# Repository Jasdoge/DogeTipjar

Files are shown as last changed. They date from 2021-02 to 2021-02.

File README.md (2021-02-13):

# DogeTipjar
A fancy dog-based internet currency tipjar

# Parts needed

* 1000 uF Capacitor (suggested 10V+)
* [ESP32 Dev board](https://www.aliexpress.com/item/32866131814.html) - You can use any ESP32 board style, but the 3D printed case was designed for that particular style
* [DFPlayer Mini](https://www.aliexpress.com/item/32657798948.html)
* SD Card for your DFPlayer
* [Small speaker](https://www.aliexpress.com/item/32901680862.html)
* [TFT Touch Screen](https://www.aliexpress.com/item/32960934541.html) - The one I used is using the ILI9341 for control and 320x240 resolution. You can use other styles if you want to edit the images & code.
* Wires

# Schematics
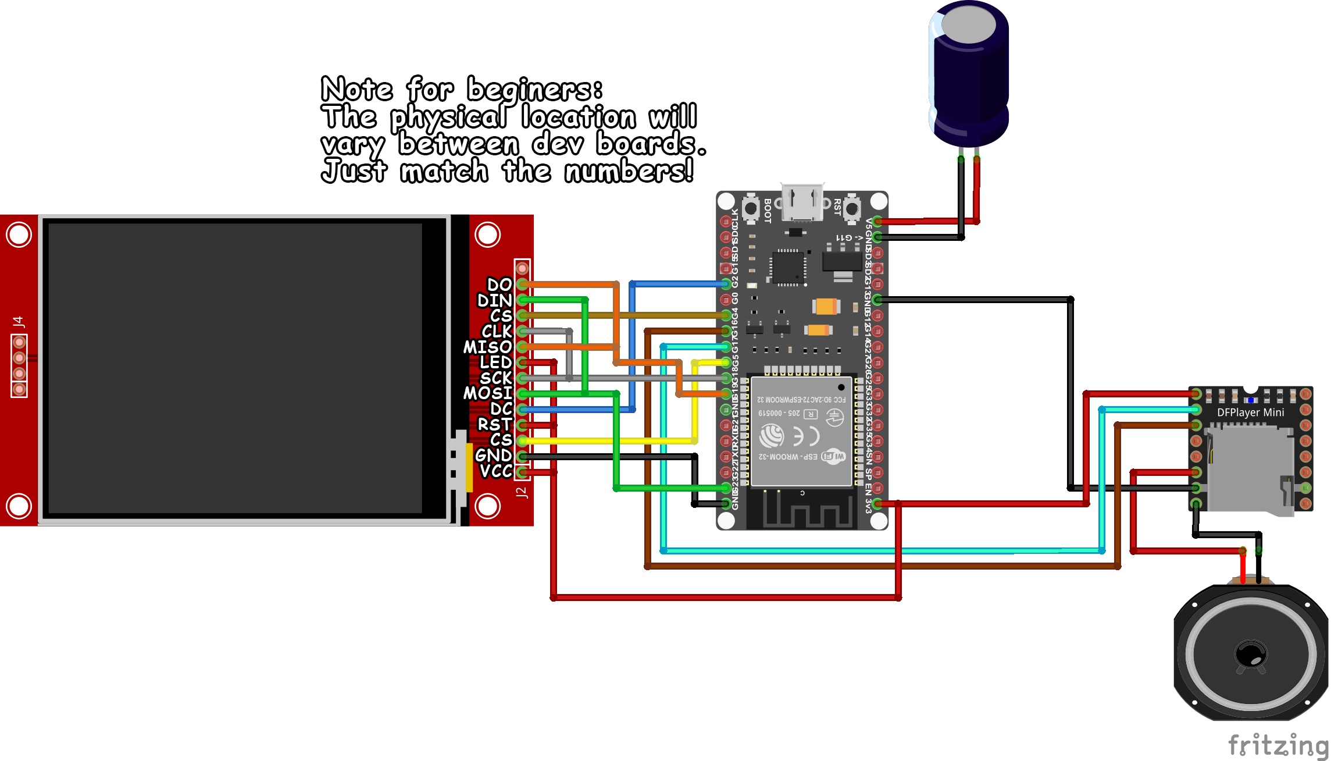
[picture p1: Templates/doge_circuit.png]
Schematics


## Touchscreen

| Screen Pin(s) | ESP Pin | Note |
|---|---|---|
| VCC, LED, RST | 3v3 | Power supply |
| GND | gnd | ESP ground, all grounds are tied together |
| CS | IO5 | Chip select for screen |
| DC | IO2 | |
| SDI (MOSI), DIN (Touch) | 23 | SPI |
| SCK, CLK (Touch) | 18 | SPI Clock |
| MISO, DO | 19 | SPI |
| IRQ (touch) | Not connected | Can be used for interrupts |
| CS | 4 | Chip select for touch |

## DFPlayer Mini

DFPlayer
| Speaker Pin | ESP Pin | Note |
|---|---|---|
| 1 (VCC) | 3v3 | Power supply |
| 2 (RX) | 17 | UART |
| 3 (TX) | 16 | UART |
| 6 | Connect to speaker | Either pole on the speaker will work |
| 7 | GND | Connect to any ground, all grounds are tied together |
| 8 | Connecto to speaker | 6 and 8 should be connected to one pole each of the speaker | 

Protip: On the bottom of the DFPlayer next to the 8-pin chip directly under the SD card is a 0-ohm resistor. If you remove that and short the unsoldered jumper on the right side of the chip, it'll draw much less current in standby.

## Capacitor

Connect a 100-1000uF capacitor with the positive end (long leg) on 5V of the ESP32, and short leg on GND. This will help reduce screen flicker and brownouts on the DFPlayer. 

# How to program

1. [Install Arduino](https://www.arduino.cc/)
2. [Install ESP32 board](https://github.com/espressif/arduino-esp32)
3. [Install the ESP32 filesystem uploader](https://randomnerdtutorials.com/install-esp32-filesystem-uploader-arduino-ide/)
4. Install the following libraries using the Arduino library manager:
	* TFT_eSPI. This one needs you to edit a User_Setup.h library file for your board. There's an example User_Setup.h in the Templates folder setup for the ILI9341 screen that I use in this project. For more info [see the library](https://github.com/Bodmer/TFT_eSPI). 
	* QRCode
	* ArduinoJson
	* ArduinoWebsockets
	* DFPlayerMini_Fast
5. Set your board appropriately in Arduino. I use ESP32 Dev module, No OTA (2MB App/2MB FATFS)
6. Open the TipJar.ino file in Arduino.
7. Plug in your arduino to your computer and select the com port in the tools menu.
8. Go to Tools -> ESP32 Sketch data upload. This should upload all the image files and font to your ESP32.
9. Audio: Format your SD card to FAT32.
10. Find the audio files in the Audio folder. The files need to be pasted in a specific order. Look at Instructions.txt in the Audio folder for the correct sequence.
11. Plug the SD card into the DFPlayer.
12. Compile and upload by hitting the Arrow button in Arduino.

# Case

The STL folder has the 3d prints. It's very simple and requires you to use hot glue to attach the screen. Feel free to make a better one!

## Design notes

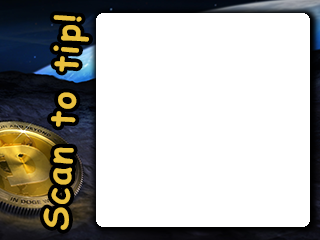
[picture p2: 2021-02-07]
Templates/qr.bmp

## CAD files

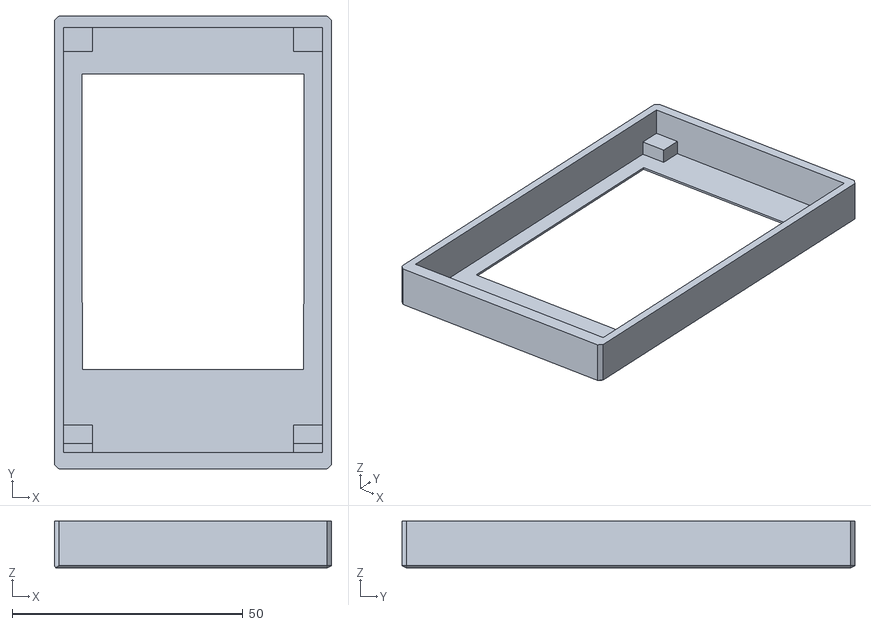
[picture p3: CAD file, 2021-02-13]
STL/screenholder.STL
60.0 x 98.1 x 10.1

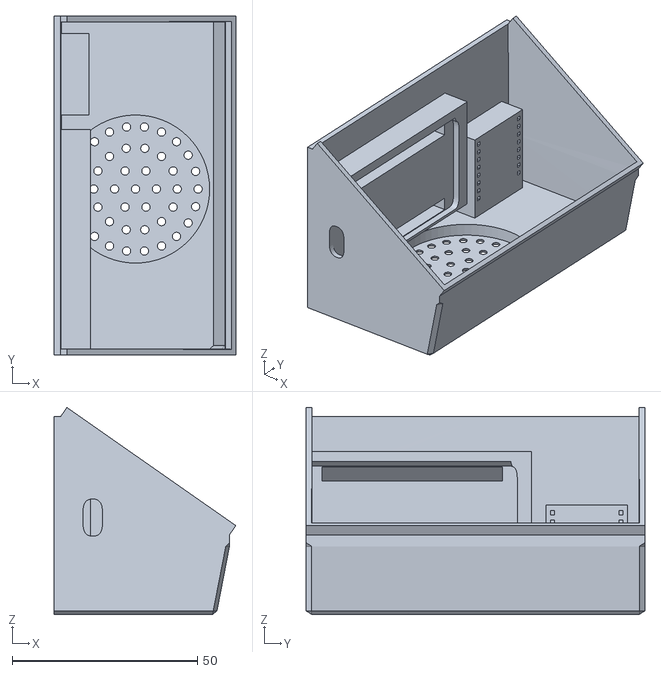
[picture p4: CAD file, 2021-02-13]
STL/dogebox_base.STL
49.1 x 91.6 x 55.9

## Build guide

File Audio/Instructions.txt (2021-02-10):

Note: The order you paste these into your SD card matters!

1. Format your SD card to FAT32
2. Copy and paste the files onto the card one by one in the following order:
	1. dogetip_big.mp3
	2. dogetip_med.mp3
	3. dogetip_small.mp3
	4. click.mp3

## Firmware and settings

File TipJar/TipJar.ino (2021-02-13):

/*
	Edit Configuration.h
	Don't forget to edit your TFT_eSPI config in libraries
	You can find a template in Templates

	Libraries:
	https://github.com/Bodmer/TFT_eSPI
	https://github.com/ricmoo/QRCode
	https://github.com/bblanchon/ArduinoJson
	https://github.com/gilmaimon/ArduinoWebsockets
	https://github.com/PowerBroker2/DFPlayerMini_Fast


	Audio credits 
	https://freesound.org/people/Robinhood76/sounds/63814/
	https://freesound.org/people/clairinski/sounds/184372/
	https://freesound.org/people/Anthousai/sounds/336578/
	https://freesound.org/people/EminYILDIRIM/sounds/536108/
*/
#include "Configuration.h"
#include "DisplayManager.h"
#include "WebsocketManager.h"
#include "SoundManager.h"
#include "ConnectionManager.h"
#include "LogManager.h"

void onWifiCredentials( String ssid = "", String pass = "" );



uint32_t last_rec = 0;			// Timestamp when we last received a tip
uint32_t last_screensav = 0; 	// 
bool screensav_active = false;

// Info screen ticks
int8_t boot_ticks = 0;
uint32_t boot_time = 0;	// Time when we first showed the settings screen
bool initialized = false;
bool addrWarning = false;	// Warned about address changed

bool connected(){
	return WebsocketManager::connected && ConnectionManager::connected;
}

void onTipReceived( uint32_t amount ){

	last_rec = millis();

	uint8_t sound = SoundManager::SOUND_MONEY_SMALL;
	if( amount >= SOUND_BIG_THR )
		sound = SoundManager::SOUND_MONEY_LARGE;
	else if( amount >= SOUND_MED_THR )
		sound = SoundManager::SOUND_MONEY_MED;
	
	SoundManager::play(sound);
	DisplayManager::setScreenDogeReceived(amount);

	LogManager::addPaymentLog(amount);

}

void onDisconnect(){

	// Try to reconnect
	onWifiCredentials("", "");

}

// When everything has been initialized, run this
void onWebsocketsSetup(){
	
	DisplayManager::setScreenQR(LogManager::RECEIVING_ADDRESS);

	if( !initialized ){
		initialized = true;
		SoundManager::play(SoundManager::SOUND_MONEY_MED);
	}

}


void onWebsocketsDisconnect(){

	if( !ConnectionManager::connected )
		return;
	DisplayManager::setScreenConnectingWebsocket();
	WebsocketManager::reconnect( LogManager::RECEIVING_ADDRESS, onWebsocketsSetup );

}

void drawBootScreen( bool force = false ){

	// Set intro screen
	if( !boot_time || force ){

		boot_time = millis();
		boot_ticks = LogManager::RECEIVING_ADDRESS.length() && !force ? 5 : -1;

		DisplayManager::setScreenSettings( 
			LogManager::total_tips, 
			LogManager::RECEIVING_ADDRESS, 
			LogManager::address_changed 
		);
		DisplayManager::setScreenSettingsTicks(boot_ticks);
		if( LogManager::RECEIVING_ADDRESS.length() )
			DisplayManager::setScreenSettingsEnableContinue();
		DisplayManager::setScreenSettingsVolume(LogManager::volume);

	}else{
		onWifiCredentials();	// Setup wifi
	}

}

// Attempt a wifi connection
bool wifiConnect( String ssid = "", String pass = "" ){

	DisplayManager::setScreenConnecting();
	if( !ConnectionManager::autoConnect(ssid, pass, DisplayManager::setScreenConnectingTicks) ){

		DisplayManager::setScreenConnectionFailed();
		delay(3000);
		return false;

	}

	// Connected

	// We changed the address this session, so we need to note a unix time
	if( !LogManager::address_changed )
		LogManager::setAddress( LogManager::RECEIVING_ADDRESS, ConnectionManager::getTime() );
	
	#ifndef HARD_WALLET
	if( !addrWarning ){
		DisplayManager::setScreenAddressChanged( ConnectionManager::getTime()-LogManager::address_changed );
		delay(4000);
	}
	#endif
	onWebsocketsDisconnect();	// Connect to WS
	
	return true;

}

// Callback for when wifi credentials have been entered into the device
void onWifiCredentials( String ssid, String pass ){

	// All connected, business as usual
	if( !wifiConnect(ssid, pass) )
		DisplayManager::setScreenNetworkScan( onWifiCredentials );	// Recurse until you fix it >:[
	

}

void onDisplayEvent( uint8_t evt, uint32_t i = 0, String s = "" ){

	if( evt == DisplayManager::EVT_TOUCH ){

		uint16_t x = i>>16;
		uint16_t y = i&0xFFFF;
		Serial.printf("onTouch %i, %i, %i\n", DisplayManager::MENU, x, y);
		// Retry connection, because it's more likely that we just lost the usual wifi
		if( DisplayManager::MENU == DisplayManager::MENU_RESCAN )
			onWifiCredentials();
		// Go to next screen (only works after the first cycle)
		else if( DisplayManager::MENU == DisplayManager::MENU_DEFAULT )
			last_screensav = 0;
		// Halt the start screen countdown
		else if( boot_ticks > -1 && DisplayManager::MENU == DisplayManager::MENU_SETTINGS ){

			boot_ticks = -1;
			DisplayManager::setScreenSettingsTicks(boot_ticks);

		}

	}
	else if( evt == DisplayManager::EVT_ADDR ){

		// This is done before the time is synced, so write 0
		LogManager::setAddress( s, 0 );
		drawBootScreen( true );

	}
	else if( evt == DisplayManager::EVT_CONTINUE )
		drawBootScreen();
	else if( evt == DisplayManager::EVT_KEYBOARD_CANCEL ){

		// Go back to scan
		if( DisplayManager::MENU == DisplayManager::MENU_PASSWD )
			DisplayManager::setScreenNetworkScan( onWifiCredentials );
		else
			drawBootScreen(true);

	}

	else if( evt == DisplayManager::EVT_VOLUME ){
		
		uint8_t vol = LogManager::volume;
		if( i )
			++vol;
		else if( vol )
			--vol;

		LogManager::setVolume(vol);
		SoundManager::setVolume(LogManager::volume);	// Doing it this way lets logmanager set limits
		DisplayManager::setScreenSettingsVolume(LogManager::volume);

	}
	else if( evt == DisplayManager::EVT_BUTTON_CLICK ){

		SoundManager::play(SoundManager::SOUND_CLICK);

	}

	else if( evt == DisplayManager::EVT_RESET_TIPS ){

		LogManager::resetTips();
		drawBootScreen(true);

	}
		

}


void setup(){
	
	Serial.begin(115200);
	delay(100);
	Serial.println("IT BEGINS");

	Serial.println("Setup display");
	DisplayManager::setup( onDisplayEvent );
	SoundManager::setup();

	ConnectionManager::setup(onDisconnect);

	// Setup SPIFFS
	if( !SPIFFS.begin() ){
		Serial.println("SPIFFS initialisation failed!");
		while (1) yield(); // Stay here twiddling thumbs waiting
	}
	Serial.println("\r\nSPIFFS available!");

	LogManager::setup();

	SoundManager::setVolume(LogManager::volume);

	// Setup callbacks and such
	WebsocketManager::setup( onTipReceived, onWebsocketsDisconnect );
	
	drawBootScreen();

}


void loop(){


	ConnectionManager::loop();
	WebsocketManager::loop();
	DisplayManager::loop();

	const uint32_t ms = millis();

	// Send test on serial to test doge tips received
	if( Serial.available() ){

		String input = Serial.readStringUntil('\n');
		if( input == "test" ){
			onTipReceived(1000);
		}
		else if( input == "factoryReset" ){
			
			Serial.println("Performing factory reset");
			LogManager::factoryReset();
			ConnectionManager::factoryReset();
			Serial.println("Reset completed");
			delay(1000);
			ESP.restart();
			delay(1000);

		}

	}

	// In boot menu
	if( boot_ticks > -1 ){

		if( ms-boot_time > 1000 ){
			boot_time = ms;
			--boot_ticks;
			if( boot_ticks == -1 ){
				drawBootScreen();	// Since boot_time is nonzero, this initiates
			}
			else
				DisplayManager::setScreenSettingsTicks(boot_ticks);
		}

		return;
	}
	
	if( !connected() )
		return;

	// Handle tip display
	if( last_rec && ms - last_rec > TIP_TIME ){
		
		last_rec = 0;
		last_screensav = ms;
		screensav_active = false;
		DisplayManager::setScreenQR(LogManager::RECEIVING_ADDRESS);

	}
	else if( last_rec )
		return;

	// Handle screensaver
	if( !screensav_active && ms - last_screensav > QR_TIME ){

		last_screensav = ms;
		screensav_active = true;
		DisplayManager::setScreenSaver();
		return;

	}

	if( screensav_active && ms - last_screensav > SCREENSAVER_TIME ){

		last_screensav = ms;
		screensav_active = false;
		DisplayManager::setScreenQR(LogManager::RECEIVING_ADDRESS);

	}


}

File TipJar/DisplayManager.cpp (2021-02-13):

#include "DisplayManager.h"
#include <WiFi.h>

// Initialization
uint8_t DisplayManager::MENU = DisplayManager::MENU_NONE;
TFT_eSPI DisplayManager::tft = TFT_eSPI();
uint32_t DisplayManager::lastTouch = 0;
uint16_t DisplayManager::wifi_buttons[5] = {0};
String DisplayManager::cache_SSID;				// Stores SSID when configuring
String DisplayManager::cache_text;			// Stores password when configuring
void (*DisplayManager::cache_wifiCallback)(String ssid, String passwd);
void (*DisplayManager::onEvent)(uint8_t event, uint32_t i, String t);
uint16_t DisplayManager::keypad_btns[KEYBOARD_LENGTH*2] = {0};	// X/Y 
bool DisplayManager::keyboardUpperCase = false;
bool DisplayManager::settingsContinueButtonEnabled = false;

void DisplayManager::setup( void(*onEventHandler)(uint8_t event, uint32_t i, String t) ){

	onEvent = onEventHandler;
	// TFT loading
	tft.init();
	tft.setRotation(1);
	tft.loadFont("ComicSans");	
	tft.setTextDatum(MC_DATUM);
	tft.setTextColor(TFT_YELLOW);
	tft.fillScreen(0);
	tft.drawString("Loading", 160, 130);


}




void DisplayManager::loop(){

	const uint32_t ms = millis();

	uint16_t t_x = 0, t_y = 0; // To store the touch coordinates

	// Touchscreen handler 

  	// Pressed will be set true is there is a valid touch on the screen
  	bool pressed = tft.getTouch(&t_x, &t_y);
	if( pressed ){

		const uint32_t l = lastTouch;
		lastTouch = ms;
		if( l )
			return;

		t_y = 240-t_y;	// May need to comment this out

		onEvent(EVT_TOUCH, (t_x<<16)|t_y, "");

		Serial.printf("%ix, %iy\n", t_x, t_y);

		// WiFi SSID Listing
		if( MENU == MENU_SSID ){

			// Scan the buttons
			for( uint8_t i = 0; i < 5; ++i ){

				uint16_t y = wifi_buttons[i];
				if( !y )
					break;

				if(checkClick(
					t_x, t_y,
					WIFI_BUTTON_LEFT,
					WIFI_BUTTON_WIDTH+WIFI_BUTTON_LEFT,
					y, 
					y+WIFI_BUTTON_HEIGHT-WIFI_BUTTON_PADDING_BOTTOM
				)){

					cache_SSID = WiFi.SSID(i);
					if( WiFi.encryptionType(i) == WIFI_AUTH_OPEN ){
						cache_wifiCallback(cache_SSID, "");
					}
					else{
						setScreenNetworkPassword();
					}

					break;

				}

			} 

		}

		// Password keypad scanning
		else if( MENU == MENU_PASSWD || MENU == MENU_ADDRESS ){

			if(checkClick(
				t_x, t_y,
				KEYBOARD_DONE_BTN_POS_X,
				KEYBOARD_DONE_BTN_POS_X+KEYBOARD_DONE_BTN_WIDTH,
				KEYBOARD_DONE_BTN_POS_Y,
				KEYBOARD_DONE_BTN_POS_Y+KEYBOARD_DONE_BTN_HEIGHT
			)){

				if( MENU == MENU_PASSWD ){
					cache_wifiCallback(cache_SSID, cache_text);
					
				}
				else{
					onEvent(EVT_ADDR, 0, cache_text);
				}
				cache_SSID = cache_text = "";

				return;
			}

			if(checkClick(
				t_x, t_y,
				10,
				10+KEYBOARD_DONE_BTN_WIDTH,
				KEYBOARD_DONE_BTN_POS_Y,
				KEYBOARD_DONE_BTN_POS_Y+KEYBOARD_DONE_BTN_HEIGHT
			)){
				cache_SSID = cache_text = "";
				onEvent(EVT_KEYBOARD_CANCEL, 0, "");
				return;
			}

			for( uint8_t i = 0; i < KEYBOARD_LENGTH; ++i ){

				const uint16_t x = keypad_btns[i*2];
				const uint16_t y = keypad_btns[i*2+1];

				if(checkClick(
					t_x, t_y,
					x, x+KEYBOARD_BTN_WIDTH,
					y, y+KEYBOARD_BTN_HEIGHT
				)){

					const char *keymap = keyboardUpperCase ? KEYBOARD_MAP_UPPERCASE : KEYBOARD_MAP_LOWERCASE;
					char pushed = keymap[i];
					if( pushed == '^' ){
						keyboardUpperCase = !keyboardUpperCase;
					}
					else if( pushed == '<' && cache_text.length() ){
						cache_text = cache_text.substring(0, cache_text.length()-1);
						drawTextEditor( MENU == MENU_PASSWD );
					}
					else if( MENU != MENU_ADDRESS || cache_text.length() < 34 ){

						cache_text += String(pushed);
						drawTextEditor( MENU == MENU_PASSWD );

					}
					drawKeyboard();

					break;

				}

			}


		}

		else if( MENU == MENU_SETTINGS ){

			#ifndef HARD_WALLET
			// Address button clicked
			if(checkClick(
				t_x, t_y,
				CENTER-60,
				CENTER+60,
				SETTING_LINES_START_Y+SETTING_LINES_HEIGHT*4,
				SETTING_LINES_START_Y+SETTING_LINES_HEIGHT*4+WIFI_BUTTON_HEIGHT
			)){
				setScreenAddress();
			}
			#endif

			// Continue button
			if(
				settingsContinueButtonEnabled &&
				checkClick(
					t_x, t_y,
					CENTER-60,
					CENTER+60,
					SETTING_LINES_START_Y+SETTING_LINES_HEIGHT*4+WIFI_BUTTON_HEIGHT+5,
					SETTING_LINES_START_Y+SETTING_LINES_HEIGHT*4+WIFI_BUTTON_HEIGHT+5+WIFI_BUTTON_HEIGHT
				)
			){
				onEvent(EVT_CONTINUE, 0, "");
			}

			// Volume minus button
			if(checkClick(
				t_x, t_y,
				VOLUME_BUTTON_X,
				VOLUME_BUTTON_X+VOLUME_BUTTON_WIDTH,
				VOLUME_BUTTON_Y-8,
				VOLUME_BUTTON_Y-8+VOLUME_BUTTON_WIDTH
			)){
				onEvent(EVT_VOLUME, 0, "");
			}

			// Volume plus button
			if(checkClick(
				t_x, t_y,
				VOLUME_BUTTON_X+VOLUME_BUTTON_WIDTH+2,
				VOLUME_BUTTON_X+VOLUME_BUTTON_WIDTH+2+VOLUME_BUTTON_WIDTH,
				VOLUME_BUTTON_Y-8,
				VOLUME_BUTTON_Y-8+VOLUME_BUTTON_WIDTH
			)){
				onEvent(EVT_VOLUME, 1, "");
			}

			// Reset tips
			if(checkClick(
				t_x, t_y,
				SETTING_LINES_START_X,
				SETTING_LINES_START_X+RESET_BUTTON_WIDTH,
				SETTING_LINES_START_Y+SETTING_LINES_HEIGHT-8,
				SETTING_LINES_START_Y+SETTING_LINES_HEIGHT-8+VOLUME_BUTTON_WIDTH
			)){
				onEvent(EVT_RESET_TIPS, 0, "");
			}

		}

		

	}
	else if( ms-lastTouch > 100 )
		lastTouch = 0;


}


// Check if a click is within boundsand draws a rect and raises an event in that case
bool DisplayManager::checkClick( uint16_t x, uint16_t y, uint16_t xMin, uint16_t xMax, uint16_t yMin, uint16_t yMax ){

	if( x >= xMin && x <= xMax && y >= yMin && y <= yMax ){

		onEvent(EVT_BUTTON_CLICK, 0, "");
		tft.fillRect(xMin, yMin, xMax-xMin, yMax-yMin, 0xFFFF);
		delay(50);
		return true;

	}
	return false;

}




// SCREENS

// Connecting screen
void DisplayManager::setScreenConnecting(){
	
	MENU = MENU_NONE;
	tft.setTextColor(TFT_YELLOW);
	tft.setTextSize(2);
	tft.fillScreen(TFT_BLACK);
	tft.drawString("WiFi Connecting", CENTER, 20);

}
void DisplayManager::setScreenConnectingTicks( uint8_t ticks ){
	
	tft.fillRect(0, 100, 320, 40, TFT_BLACK);
	uint16_t start = CENTER-ticks*6/2;
	for( uint8_t i = 0; i < ticks; ++i ){

		tft.fillRect(start+1+i*6, 120, 4, 4, 0xFFFF);

	}

}

void DisplayManager::setScreenConnectingWebsocket(){
	MENU = MENU_NONE;

	tft.setTextColor(TFT_YELLOW);
	tft.setTextSize(2);
	tft.fillScreen(TFT_BLACK);
	tft.drawString("Connecting to dogechain", CENTER, 20);

}

void DisplayManager::setScreenConnectionFailed(){
	MENU = MENU_NONE;
	tft.fillScreen(TFT_BLACK);
	tft.drawString("Connection failed", CENTER, 20);
		
}


void DisplayManager::setScreenDogeReceived( uint32_t amount ){
	MENU = MENU_NONE;

	drawBmp("/doge_received.bmp");

	tft.loadFont("ComicSans");
	tft.setTextDatum(MC_DATUM);
	tft.setTextColor(TFT_YELLOW);
	
	tft.drawNumber(amount, 160, 130-40);
	tft.drawString("DOGE!", 160, 130+40);
	tft.unloadFont();

}

void DisplayManager::setScreenSaver(){
	MENU = MENU_DEFAULT;
	drawBmp("/wallpaper.bmp");

}

void DisplayManager::setScreenQR( String address ){
	MENU = MENU_DEFAULT;

	drawQrCode(address);

}
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

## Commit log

2021-02-07 IT BEGINS
    [Configuration.h]
2021-02-10 settings menu
    [Configuration.h]
2021-02-10 add unified button handler
2021-02-10 allow hardcoded address
    [Configuration.h]
2021-02-13 Update STLs Add factory reset Fix button offsets for keyboards
    [dogebox_base.STL, screenholder.STL]
